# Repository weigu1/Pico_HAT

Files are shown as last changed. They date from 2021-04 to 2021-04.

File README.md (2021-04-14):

# Pico-HAT: Connect your Raspi with the Pico through I²C

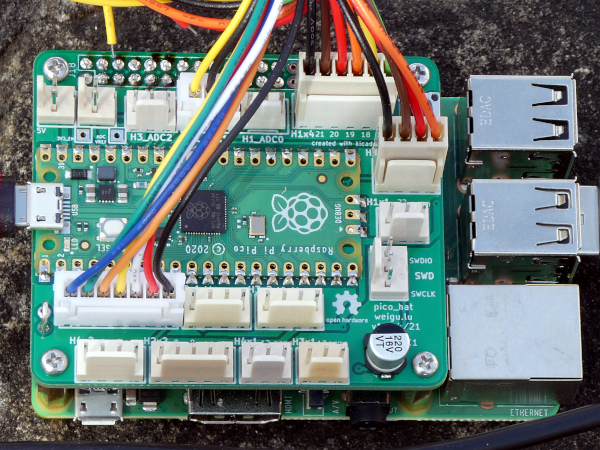
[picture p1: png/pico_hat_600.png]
pico hat


## All infos on: <http://www.weigu.lu/microcontroller/pico_hat/index.html>

## Some infos

The Pico connects to all the sensors and actuators and can act in `Real Time`. The Raspi can do the rest (Wifi, Webserver, MQTT, Display ...). The Pico is an I²C slave to the Raspi and the Raspi sends commands with a Python script to the Pico. An Arduino program on the Pico answers with sensor data or by switching an actuator.

As the Arduino IDE runs on a Raspi, both device (Raspi and Pico) can be reprogrammed via VNC from any computer, and I find this pretty amazing :).

### Features

+ The Raspi is connected through I²C with the Pico. Serial is prepared if needed (by adding 2 0&#8239;Ω resistors).

+ The Pico can be powered over USB (recommended if you want to reprogram it via Arduino IDE and VNC) or through the Raspi (5&#8239;V).

+ All GPIOs have the possibility to add a voltage divider to reduce the input voltage (e.g. 5&#8239;V to 3.3&#8239;V), or to add an external pull-down resistor.

+ All headers have beneath a ground pin, one or two power pins (3.3&#8239;V or 5&#8239;V; `H2` headers: 3.3&#8239;V and 5&#8239;V).

+ Additionally we get a RESET-button, an `SWD` header, 2 power header (3.3&#8239;V and 5&#8239;V), 2 Ground pins, an an 3V3_EN and ADC\_VREF pins.

### Circuit

The circuit is designed with KiCAD and is open hardware. The following headers are available:

| Name | Pin 1 | Pin 2 | Pin 3 | Pin 5 | Pin 5 | Pin 6 | Pin 7 |
|--|--|--|--|--|--|--|--|
| `5V_Pico` | GND | 5&#8239;V |
| `3V3_Pico` | GND | 3.3&#8239;V |
| `SWD` | SWDIO | GND | SWCLK |
| `H1_ADC0` | GND | ADC0 (GPIO26) | 3.3&#8239;V |
| `H2_ADC1` | GND | ADC1 (GPIO27) | 3.3&#8239;V |
| `H3_ADC2` | GND | ADC2 (GPIO28) | 3.3&#8239;V |
| `H1x1` | GND | GPIO22 | 3.3&#8239;V (or 5&#8239;V) |
| `H3x1` | GND | GPIO13 | 3.3&#8239;V (or 5&#8239;V) |
| `H4x1` | GND | GPIO12 | 3.3&#8239;V (or 5&#8239;V) |
| `H2x1` | GND | GPIO12 | 3.3&#8239;V | 5&#8239;V |
| `H1x2`<br>&#8239; | GND<br>&#8239; | GPIO17<br>(alt. RX0-TX_Raspi) | GPIO16<br>(alt. TX0-RX_Raspi) | 3.3&#8239;V (or 5&#8239;V)<br>&#8239; |
| `H3x2` | GND | GPIO10 | GPIO11 | 3.3&#8239;V (or 5&#8239;V) |
| `H4x2` | GND | GPIO6 | GPIO7 | 3.3&#8239;V (or 5&#8239;V) |
| `H2x2` | GND | GPIO8 | GPIO9 | 3.3&#8239;V | 5&#8239;V |
| `H1x4` | GND | GPIO21 | GPIO20 | GPIO19 | GPIO18 | 3.3&#8239;V (or 5&#8239;V) |
| `H2x4` | GND | GPIO2 | GPIO3 | GPIO4 | GPIO5 | 3.3&#8239;V | 5&#8239;V |

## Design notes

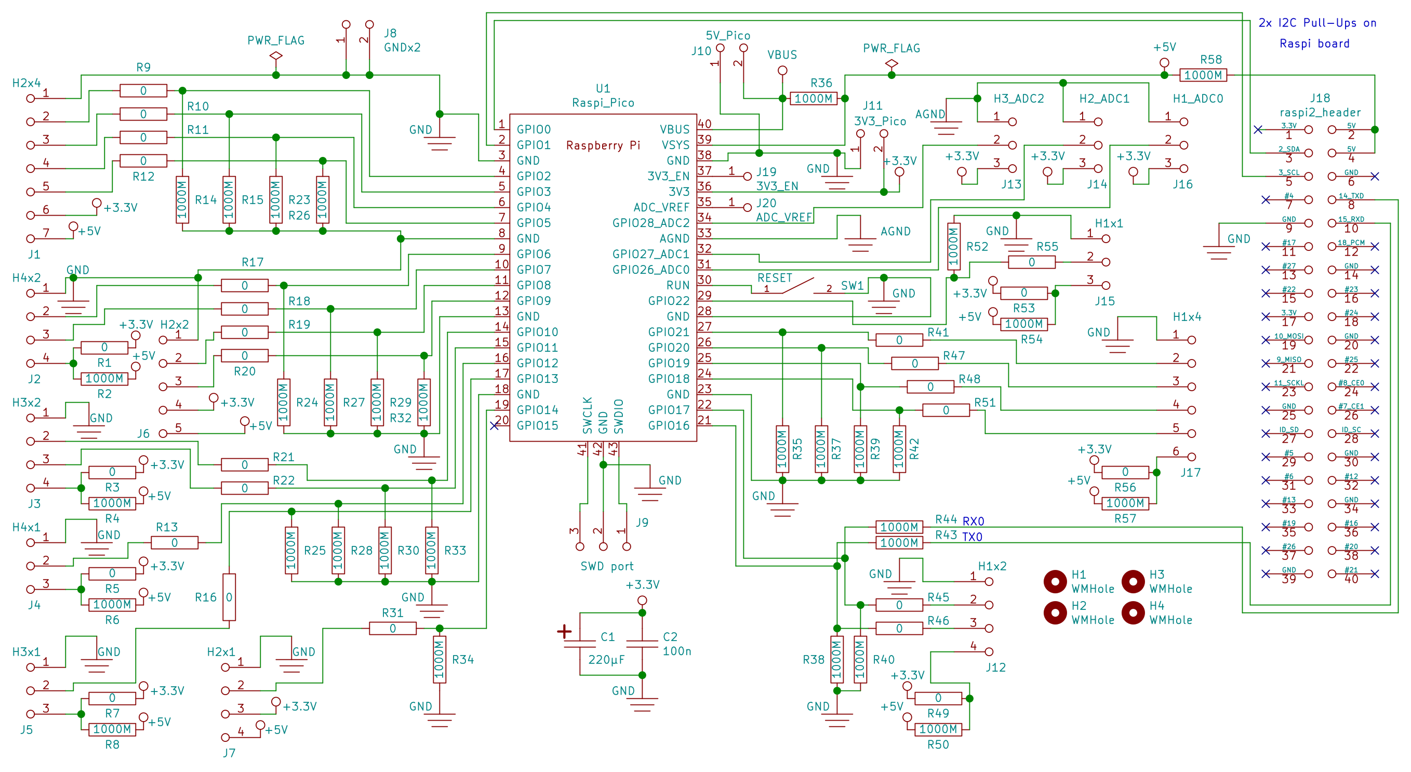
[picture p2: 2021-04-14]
KiCAD/raspi_hat_circuit.png

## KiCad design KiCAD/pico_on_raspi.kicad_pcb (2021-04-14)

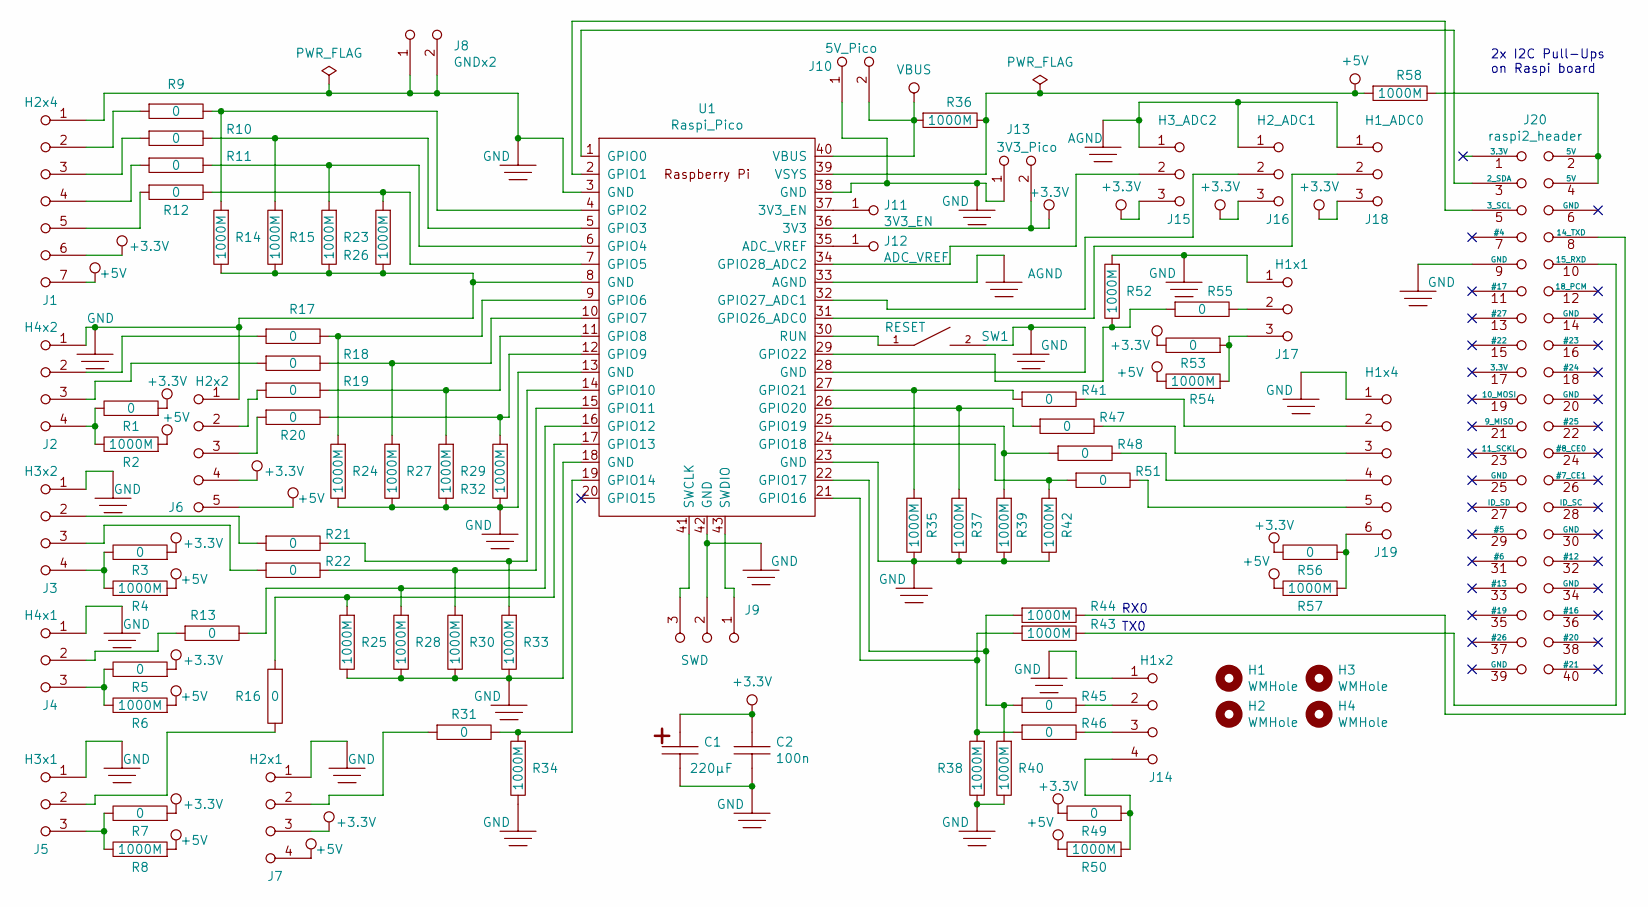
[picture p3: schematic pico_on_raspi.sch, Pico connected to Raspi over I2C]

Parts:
C1: 220µF; WC_Elec_SMD_5x5.4
C2: 100n; W0805
H1, H2, H3, H4: WMHole; WHole_2.7mm_M2.5
J1: H2x4; WSIL7_SL
J2: H4x2; WSIL4_SL
J3: H3x2; WSIL4_SL
J4: H4x1; WSIL3_SL
J5: H3x1; WSIL3_SL
J6: H2x2; WSIL5_SL
J7: H2x1; WSIL4_SL
J8: GNDx2; WSIL2_2x1
J9: SWD; WSIL3_SL
J10: 5V_Pico; WSIL2_SL
J11: 3V3_EN; WSIL1
J12: ADC_VREF; WSIL1
J13: 3V3_Pico; WSIL2_SL
J14: H1x2; WSIL4_SL
J15: H3_ADC2; WSIL3_SL
J16: H2_ADC1; WSIL3_SL
J17: H1x1; WSIL3_SL
J18: H1_ADC0; WSIL3_SL
J19: H1x4; WSIL6_SL
J20: raspi2_header; WSIL_2x20_Raspi
R1, R3, R5, R7, R9, R10, R11, R12, R13, R16, R17, R18, R19, R20, R21, R22, R31, R41, R45, R46, R47, R48, R49, R51, R53, R55, R56: 0; W0805_0_Ohm
R2, R4, R6, R8, R14, R15, R23, R24, R25, R26, R27, R28, R29, R30, R32, R33, R34, R35, R36, R37, R38, R39, R40, R42, R43, R44, R50, R52, R54, R57, R58: 1000M; W0805
SW1: RESET; WPB
U1: Raspi_Pico; WPico_RASPI

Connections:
+3.3V: C1.1, C2.1, J1.6 (16), J6.4 (14), J7.3 (13), J13.2 (12), J15.3 (13), J16.3 (13), J18.3 (13), R1.1, R3.1, R5.1, R7.1, R49.2, R53.2, R56.2, U1.36 (3V3)
+5V: J1.7 (17), J6.5 (15), J7.4 (14), R2.1, R4.1, R6.1, R8.1, R36.2, R50.2, R54.2, R57.2, R58.1, U1.39 (VSYS)
unnamed: J1.2 (12), R9.1
unnamed: J1.3 (13), R10.1
unnamed: J1.4 (14), R11.1
unnamed: J1.5 (15), R12.1
unnamed: J2.2 (12), R17.1
unnamed: J2.3 (13), R18.1
unnamed: J2.4 (14), R1.2, R2.2
unnamed: J3.2 (12), R21.1
unnamed: J3.3 (13), R22.1
unnamed: J3.4 (14), R3.2, R4.2
unnamed: J4.2 (12), R13.1
unnamed: J4.3 (13), R5.2, R6.2
unnamed: J5.2 (12), R16.2
unnamed: J5.3 (13), R7.2, R8.2
unnamed: J6.2 (12), R19.1
unnamed: J6.3 (13), R20.1
unnamed: J7.2 (12), R31.1
unnamed: J9.1 (11), U1.43 (SWDIO)
unnamed: J9.3 (13), U1.41 (SWCLK)
unnamed: J10.2 (12), R36.1, U1.40 (VBUS)
unnamed: J11.1, U1.37 (3V3_EN)
unnamed: J12.1, U1.35 (ADC_VREF)
unnamed: J14.2 (12), R45.2
unnamed: J14.3 (13), R46.2
unnamed: J14.4 (14), R49.1, R50.1
unnamed: J15.2 (12), U1.34 (GPIO28_ADC2)
unnamed: J16.2 (12), U1.32 (GPIO27_ADC1)
unnamed: J17.2 (12), R55.2
unnamed: J17.3 (13), R53.1, R54.1
unnamed: J18.2 (12), U1.31 (GPIO26_ADC0)
unnamed: J19.2 (12), R41.2
unnamed: J19.3 (13), R47.2
unnamed: J19.4 (14), R48.2
unnamed: J19.5 (15), R51.2
unnamed: J19.6 (16), R56.1, R57.1
unnamed: J20.2 (5V), J20.4 (5V), R58.2
unnamed: J20.3 (2_SDA), U1.1 (GPIO0)
unnamed: J20.5 (3_SCL), U1.2 (GPIO1)
unnamed: J20.8 (14_TXD), R43.2
unnamed: J20.10 (15_RXD), R44.2
unnamed: R10.2, R15.1, U1.5 (GPIO3)
unnamed: R11.2, R23.1, U1.6 (GPIO4)
unnamed: R12.2, R26.1, U1.7 (GPIO5)
unnamed: R13.2, R28.1, U1.16 (GPIO12)
unnamed: R9.2, R14.1, U1.4 (GPIO2)
unnamed: R16.1, R25.1, U1.17 (GPIO13)
unnamed: R17.2, R24.1, U1.9 (GPIO6)
unnamed: R18.2, R27.1, U1.10 (GPIO7)
unnamed: R19.2, R29.1, U1.11 (GPIO8)
unnamed: R20.2, R32.1, U1.12 (GPIO9)
unnamed: R21.2, R33.1, U1.14 (GPIO10)
unnamed: R22.2, R30.1, U1.15 (GPIO11)
unnamed: R31.2, R34.1, U1.19 (GPIO14)
unnamed: R35.1, R41.1, U1.27 (GPIO21)
unnamed: R37.1, R47.1, U1.26 (GPIO20)
unnamed: R38.1, R44.1, R46.1, U1.21 (GPIO16)
unnamed: R39.1, R48.1, U1.25 (GPIO19)
unnamed: R40.1, R43.1, R45.1, U1.22 (GPIO17)
unnamed: R42.1, R51.1, U1.24 (GPIO18)
unnamed: R52.2, R55.1, U1.29 (GPIO22)
unnamed: SW1.1, U1.30 (RUN)

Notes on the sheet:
RX0
TX0
2x I2C Pull-Ups on Raspi board

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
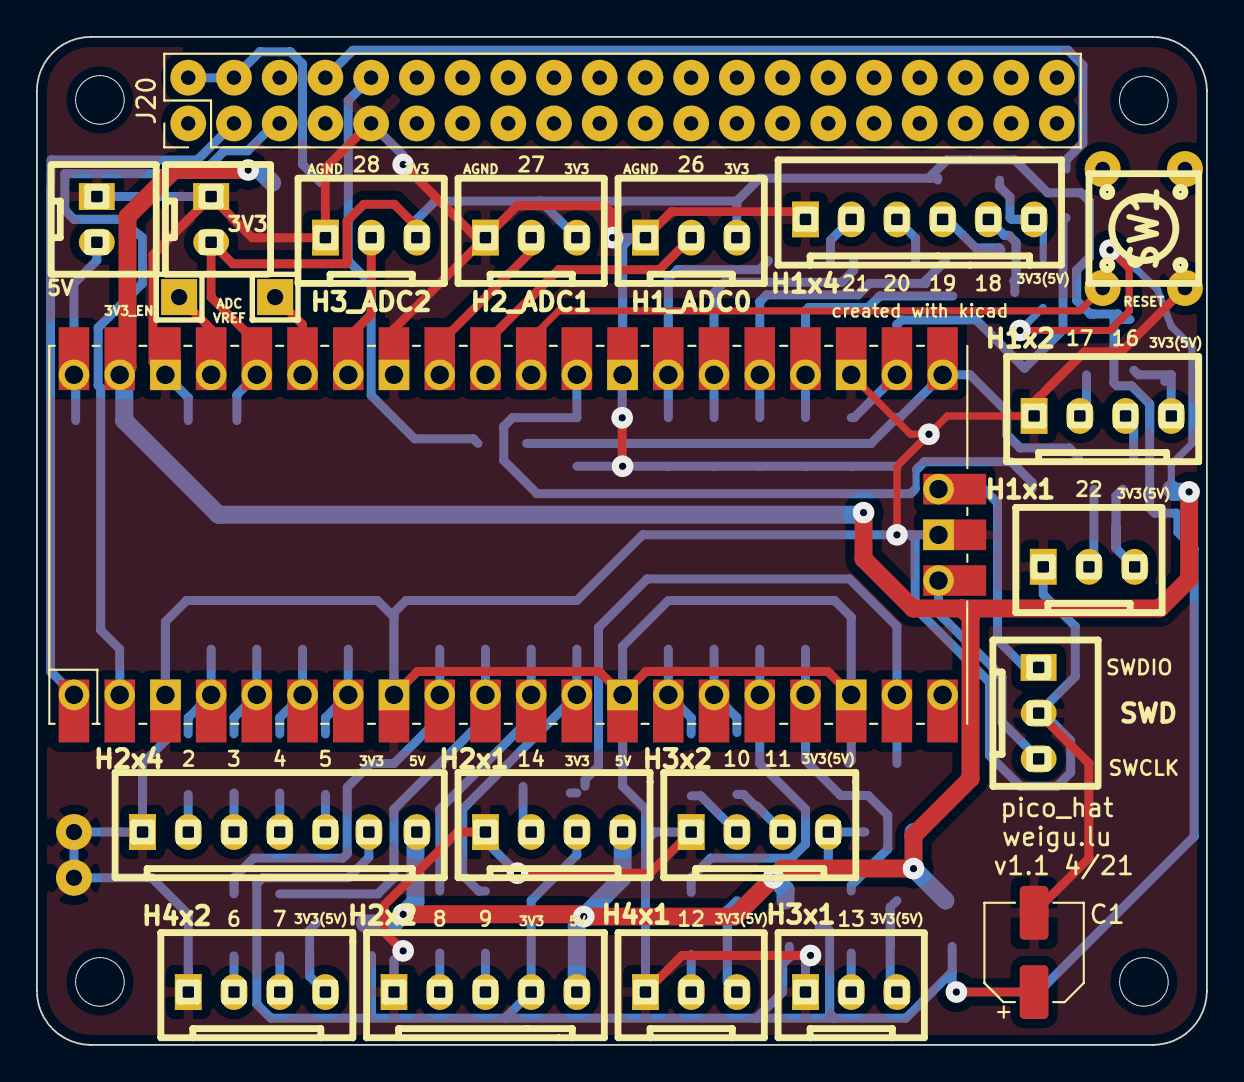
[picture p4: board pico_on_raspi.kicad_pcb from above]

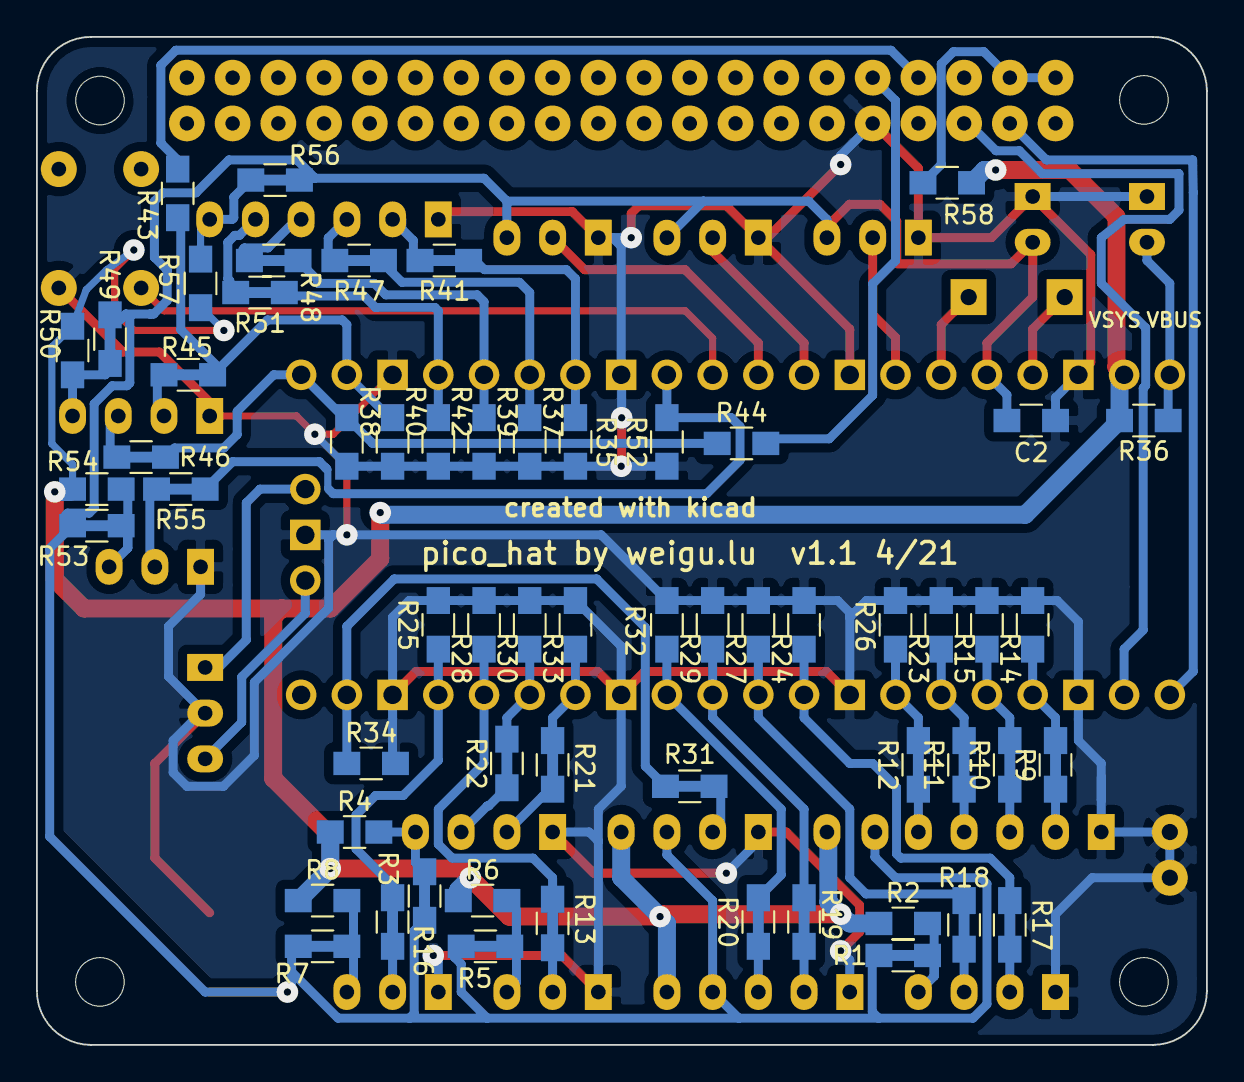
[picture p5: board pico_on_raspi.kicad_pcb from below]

Board: 2 copper layers, 65.0 x 56.0 mm, 86 parts (59 on the bottom side), 64 nets.

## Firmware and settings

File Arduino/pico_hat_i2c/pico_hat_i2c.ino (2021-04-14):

/* pico_hat_i2c.ino   weigu.lu
 * Raspberry Pi is Master, Pico is slave
 * The Raspi program sends 3 bytes to the Pico, defining how often
 * the onboard LED will blink and defining the delay time in ms between
 * the toggling (command 0x0A).
 * The pico responds with 2x2 bytes (temperature and humidity) when receiving
 * the commands 0x81 and 0x82.
 * More infos on weigu.lu
 */

#include <Wire.h>

//#define DEBUG      // uncomment if more infos needed in serial monitor

const byte PICO_I2C_ADDRESS = 0x20;
const byte LED_PIN = LED_BUILTIN;   // LED_BUILTIN or other pin
bool LED_LOGIC = 1;                 // positive logic: 1, negative logic: 0
const unsigned long DELAY_MS = 3000;
const unsigned long LED_BLINK_DELAY_MS = 100;

struct {
  float volatile t1; // temperature
  float volatile h1; // humidity
} tx_data;

struct {
  byte volatile blink_nr = 3;
  word volatile blink_delay = 100;
} rx_data;

byte volatile command = 0;
byte volatile rx_flag = 0;
byte volatile tx_flag = 0;
const byte tx_table_bytes = 20;
byte volatile tx_table[tx_table_bytes]; // prepare data for sending over I2C

void setup() {
  Serial.begin(115200);             // for debugging
  init_led();
  Wire.begin(PICO_I2C_ADDRESS);     // join i2c bus
  Wire.onReceive(i2c_receive);      // i2c interrupt receive
  Wire.onRequest(i2c_transmit);     // i2c interrupt send
  tx_data.t1 = 21.30;               // simulate a temperature
  tx_data.h1 = 60;                  // simulate humidity value
}

void loop() {
  blink_led_x_times(rx_data.blink_nr,rx_data.blink_delay);
  #ifdef DEBUG
    if (rx_flag) {
      Serial.println("RX with " + String(rx_flag) + "byte; command: " + String(command));
      rx_flag = 0;
    }
    if (tx_flag) {
      print_tx_table();
      tx_flag = 0;
    }
  #else
    delay(3000);
  #endif
}

void i2c_receive(int bytes_count) { // bytes_count gives number of bytes in rx buffer
  if (bytes_count == 0) {           //  master checked only for presence
    return;
  }
  command = Wire.read();
  switch (command) {   // parse commands
    case 0x0A:  // read three bytes (blink nr and delay time)
      rx_data.blink_nr = Wire.read();
      rx_data.blink_delay = Wire.read();
      rx_data.blink_delay = rx_data.blink_delay*256 + Wire.read();
      break;
    default:
      break;
  }
  rx_flag = bytes_count;
}

void i2c_transmit() {
  byte bytes_count = 1;
  int tmp1 = 0;                     // temporary variable
  switch (command) {
    case 0x81: // temperature
      tmp1 = int(round(tx_data.t1 * 100));
      tx_table[0] = (byte)(tmp1 & 0xFF);
      tx_table[1] = (byte)(tmp1 >> 8);
      bytes_count = 2;
      break;
    case 0x82: // humidity
      tmp1 = int(round(tx_data.h1 * 100));
      tx_table[0] = (byte)(tmp1 & 0xFF);
      tx_table[1] = (byte)(tmp1 >> 8);
      bytes_count = 2;
      break;
    default:
      break;
  }
  for (byte i = 0; i < bytes_count; i++) {
    Wire.write(tx_table[i]);
  }
  tx_flag = 1;
}

void print_tx_table() {
  Serial.println("Transmit Table");
  for (byte i = 0; i < tx_table_bytes; i++) {
    Serial.print("  " + String(i) + ": " + String(tx_table[i]));
  }
  Serial.println();
}

/****** LED HELPER functions *************************************************/

// initialise the build in LED and switch it on
void init_led() {
  pinMode(LED_PIN,OUTPUT);
  led_on();
}

// LED on
void led_on() {
  LED_LOGIC ? digitalWrite(LED_PIN,HIGH) : digitalWrite(LED_PIN,LOW);
}

// LED off
void led_off() {
  LED_LOGIC ? digitalWrite(LED_PIN,LOW) : digitalWrite(LED_PIN,HIGH);
}

// blink LED x times (LED was on) with delay_time_ms
void blink_led_x_times(byte x, word delay_time_ms) {
  for(byte i = 0; i < x; i++) { // Blink x times
    led_off();
    delay(delay_time_ms);
    led_on();
    delay(delay_time_ms);
  }
}

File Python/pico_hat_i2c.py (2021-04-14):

#!/usr/bin/env python3
# -*- coding: utf-8 -*-
''' pico_hat_i2c.py  weigu.lu
    Raspberry Pi is Master, Pico is slave
    This test program sends the 3 bytes to the Pico, defining how often
    the onboard LED will blink and defining the delay time in ms between
    the toggling (command 0x0A).
    It reads 2x2 bytes from the Arduino (temperature (0x81) and humidity (0x82)
    More infos on weigu.lu '''

import smbus

PORT = 1 # (0 for rev.1, 1 for rev 2!)
I2C = smbus.SMBus(PORT)
PICO_I2C_ADDRESS = 0x20

COMMAND_TEMP1 = 0x81  # MSB = 1 for read
COMMAND_HUM1 = 0x82
COMMAND_BLINK = 0x0A  # MSB = 0 for write
BLINK_RATE = 10       # how many times to blink (1 byte)
BLINK_DELAY = 50      # delay between toggling im ms (1 word)

def get_sensor_data(command):
    ''' write command and read data (1 word)'''
    I2C.write_byte(PICO_I2C_ADDRESS, command)
    return I2C.read_word_data(PICO_I2C_ADDRESS, command)/100.0

def set_blink(blink_command, blink_rate, blink_delay):
    ''' write to Pico: blink rate (1 byte) and delay (2 byte)'''
    blink = [] # list for 3 bytes
    blink.append(blink_rate)
    blink.append(blink_delay//256)
    blink.append(blink_delay%256)
    I2C.write_i2c_block_data(PICO_I2C_ADDRESS, blink_command, blink)

# main: try the commands
print("Temperature 1: ", get_sensor_data(COMMAND_TEMP1), "°C")
print("Humidity 1:    ", get_sensor_data(COMMAND_HUM1), "%")
set_blink(COMMAND_BLINK, BLINK_RATE, BLINK_DELAY)
